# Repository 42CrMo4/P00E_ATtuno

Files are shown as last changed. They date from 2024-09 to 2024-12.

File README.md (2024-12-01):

# KiCad ATtuno Dev board

The ATtuno is a dev board for ATtiny 1 series microcontroller, loosely based on the UNO form factor. 

## Description

The ATtuno is an excellent starting point for those looking to explore the ATtiny 1 series microcontroller platform. 
Inspired by the familiar Arduino Uno form factor, this board offers a user-friendly approach to working with ATtiny Series 1 MCUs.
Key features:

- Arduino Uno-inspired layout
- Generous board size for comfortable handling
- Robust Wago clamping pin headers for secure connections
- Designed for quick start and rapid prototyping
- 3.3V and 5V compatible

This dev board bridges the gap between the popular Arduino ecosystem and the powerful, efficient ATtiny Series 1 microcontrollers. 
Its thoughtful design allows both beginners and experienced makers to quickly dive into projects without the need for delicate handling or specialized tools.

### Goal

The goal of the project will be:
- [ ] **undefined** - not known what the project will bring 
- [ ] **learn** - personally learn something new, no usefull outcome expected
- [ ] **prototype** - a working prototype or mvp
- [x] **80-20-rule** - 80% outcome with 20% effort
- [ ] **Product** - lets see :wink:

## KiCanvas 

view the project files in the browaser without downloading or installing anything via [KiCanvas](https://kicanvas.org)

[Main branche - Development](https://kicanvas.org/?github=https%3A%2F%2Fgithub.com%2F42CrMo4%2FP00E_ATtuno)

[v3.0](https://kicanvas.org/?github=https%3A%2F%2Fgithub.com%2F42CrMo4%2FP00E_ATtuno%2Ftree%2Fv3.0)

[v2.0](https://kicanvas.org/?github=https%3A%2F%2Fgithub.com%2F42CrMo4%2FP00E_ATtuno%2Ftree%2Fv2.0)

[v1.0](https://kicanvas.org/?github=https%3A%2F%2Fgithub.com%2F42CrMo4%2FP00E_ATtuno%2Ftree%2Fv1.0)

## Rendering (V3.0)

| Font | Back |
| --- | --- |
|PCB Top design|PCB Back design|

If you are looking for the latest Release with all the artifacts please visit the Release Page

## Rendering & BOM (Dev)

The renderings and BOM below are the uptodate state of the main branche.

| Font | Back |
|---|---|
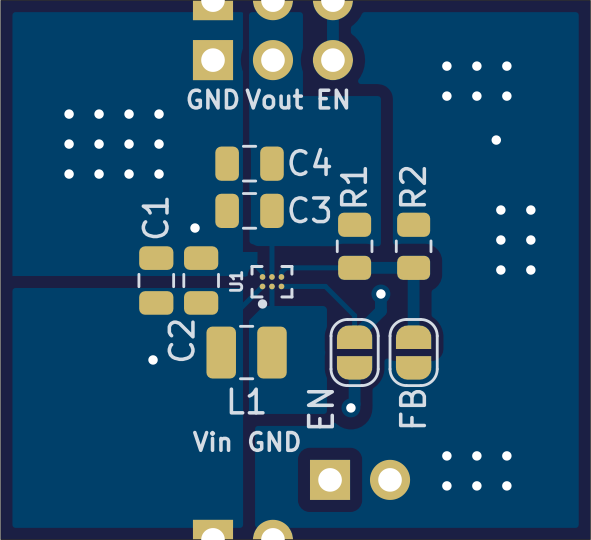
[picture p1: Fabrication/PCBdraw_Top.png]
PCB Top design
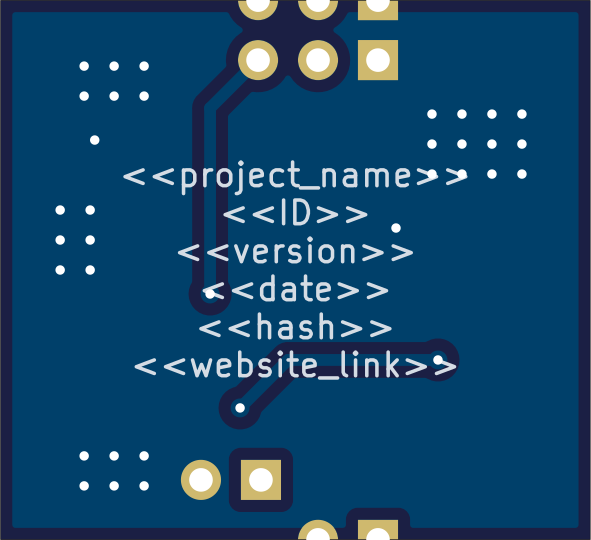
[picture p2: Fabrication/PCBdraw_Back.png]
PCB Back design
|  |  |

Link to the current BOM

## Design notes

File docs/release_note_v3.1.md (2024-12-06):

| Font | Back |
| --- | --- |
|PCB Top design|PCB Back design|

Bug Fix for Rlease Output.
No change to Schmatic or Board files

Changes
* Add Footprint Value to JLPCB Gerbers

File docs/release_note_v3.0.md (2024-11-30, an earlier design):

| Font | Back |
| --- | --- |
|PCB Top design|PCB Back design|

first RC release

New
* Added ATtiny1616 in QFN package as an option
* Added MOSFETS for the LEDs 
* Added programming capacitor for the CP2105 (see #4)
* Added Test Points 

Changes
* use PA4 / PA5 for the LEDs as this pins have PWM (see #2)
* decouple CP2105 from direct VBUS and use the DPDT switch (see #5)
* Footprint for the DPDT to habe a secound source option
* more information for BOM and components

Breaking Changes
* removed jumper for LEDs
* stencil fom v2.0 mostly not compatible

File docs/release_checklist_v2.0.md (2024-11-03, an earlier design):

Check before releasing and/or submitting to FAB
- [x] DRC/ERC passing (no Errors)
- [x] check for unconnected Traces
- [x] Groundplanes (newly) filled
- [x] Dimension Outline
- [x] Mounting Holes
- [x] Clearance for Connectors
- [x] Clearance for Housing
- [x] Clearance for generell
- [x] Component Labels
- [x] Labels not over VIA or Holes etc. 
- [x] Label Important (All) Pins — Both Sides
- [x] Revision number of Checklist will match the Git tag
- [x] Double check the final files
- [x] Fill Changelog (release_note.md)
- [x] projekt.properties filled correctly
- [x] Weblink / version / Date / name present SCH
- [x] Weblink / version / Date / name present PCB
- [x] Power Trace correct width
- [x] decoupling capacitors present
- [x] component orientation correct (MCU, Diod, etc)

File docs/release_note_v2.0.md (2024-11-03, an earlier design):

| Font | Back |
| --- | --- |
|PCB Top design|PCB Back design|

This is the 2nd iteration with a lot of improvmenets. 

New
* CP2105 USB to UPDI and UART
* StemmaQT Connector
* 4x4 WS2812b Grid 
* Dual Connectors for Pins and Slide Switches
* Mounting Holes M2.5
* TVS USB protection
* Test Points 
* Test Points with Hooks

Changes
* Silkscreen Updates for better Information

Breaking Changes
* Solder Stencil form v1.0 (many components have a diffent position and some new)
* use LED Pins PB0, PB1, PC0
* use RX/TX main Pins PB2, PB3 instead of secondary

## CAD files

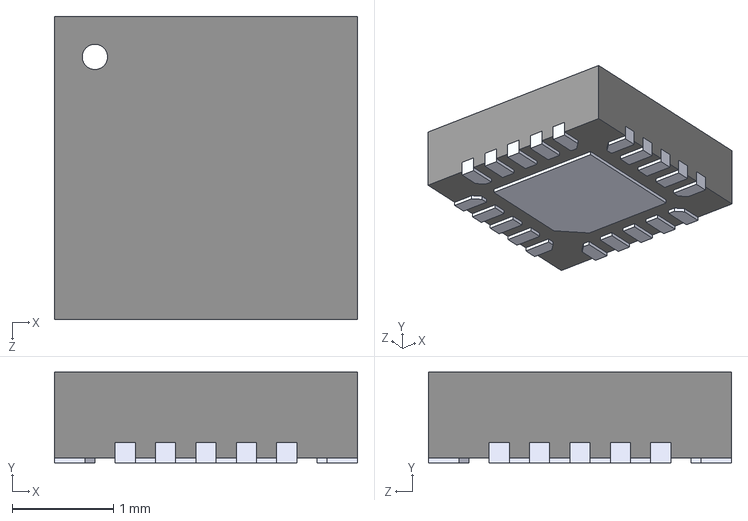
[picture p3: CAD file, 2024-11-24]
3d-models/ATTINY1616-MFR.step
3.00 x 0.9 x 3.00 mm

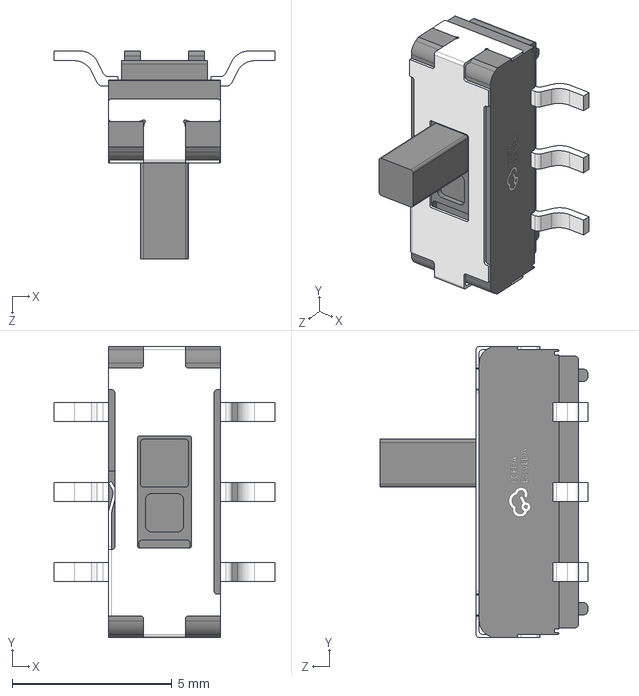
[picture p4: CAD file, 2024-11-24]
3d-models/SW-SMD_K3-2235S-K1.step
6.90 x 9.10 x 6.50 mm
翋极
褲极

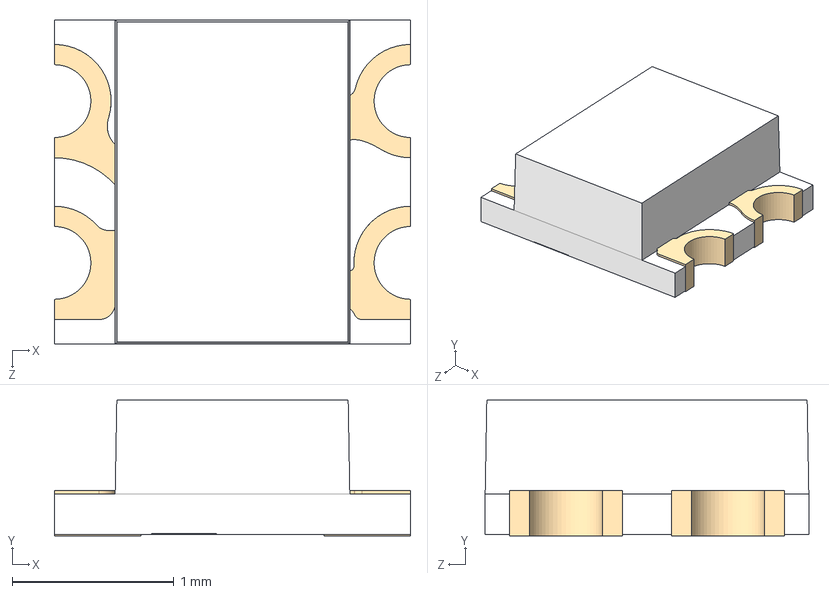
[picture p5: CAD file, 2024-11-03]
3d-models/WS2812B-2020.step
2.20 x 0.84 x 2.00 mm

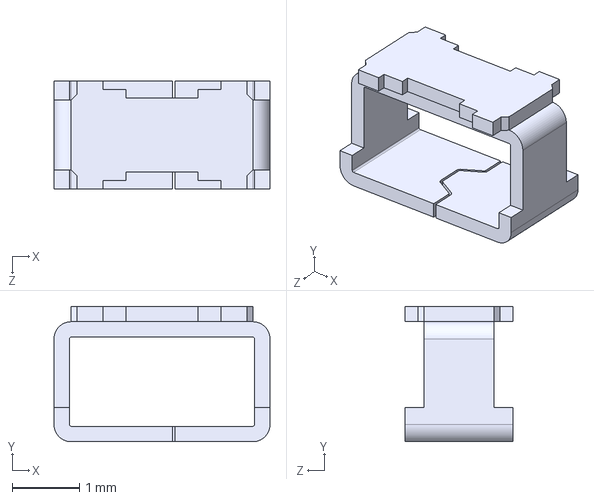
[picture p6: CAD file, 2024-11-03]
3d-models/RCWCTE.step
3.20 x 2.01 x 1.60 mm

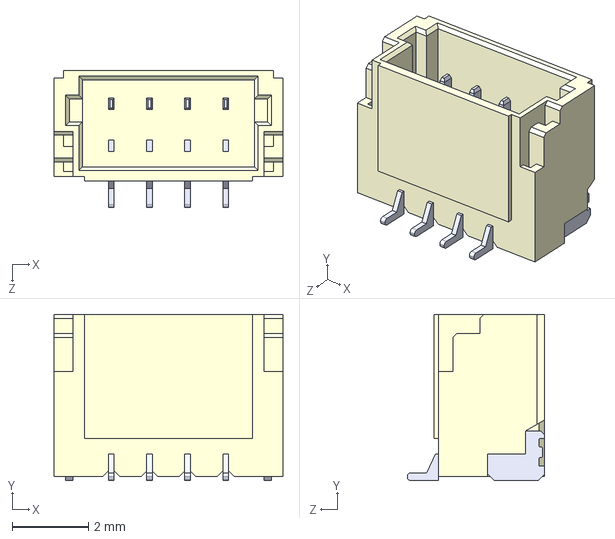
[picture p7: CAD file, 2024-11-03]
3d-models/BM04B-SRSS-TB_LF__SN_.step
6.00 x 4.35 x 3.60 mm

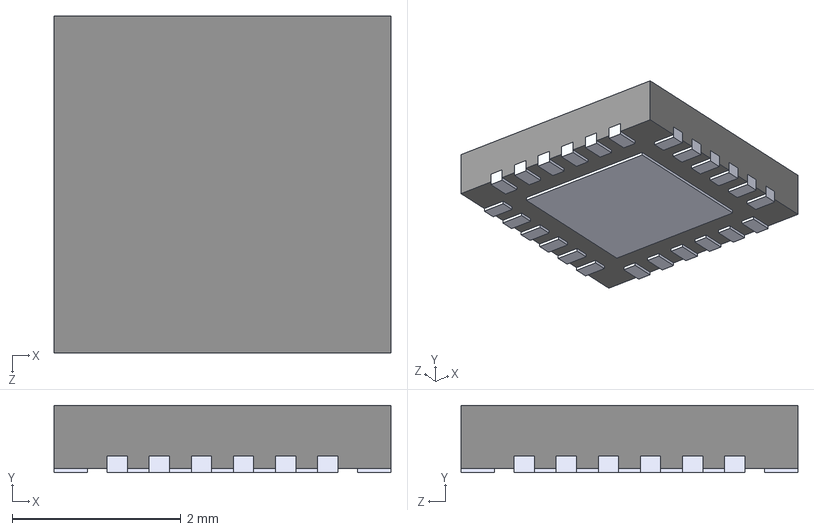
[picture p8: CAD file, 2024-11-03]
3d-models/CP2105.step
4.00 x 0.8 x 4.00 mm

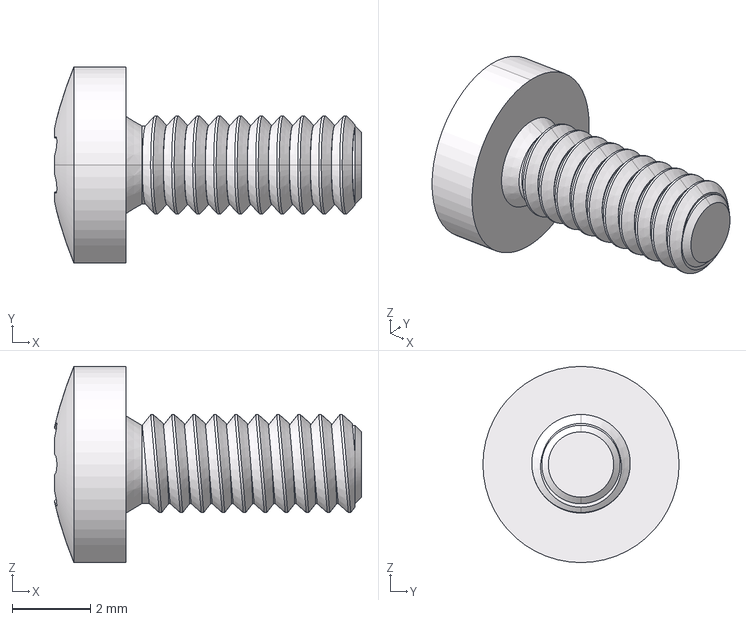
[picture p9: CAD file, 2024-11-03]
3d-models/Wuerth_0046662506_DIN_7985_aehnlich_Stahl_8.8_verzinkt_TX_LOD_High_1.stp
7.83 x 5.00 x 5.00 mm

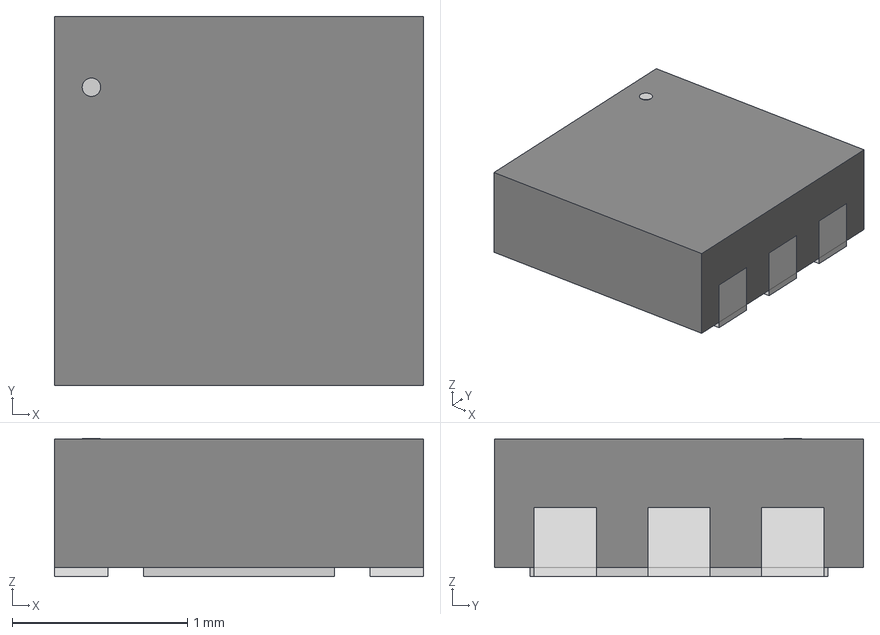
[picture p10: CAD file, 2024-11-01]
3d-models/DFN2X2-6-A_TPK.step
2.11 x 2.11 x 0.79 mm

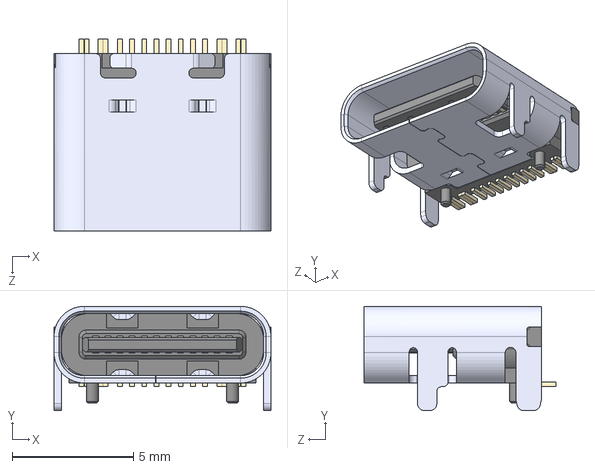
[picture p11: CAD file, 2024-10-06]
3d-models/TYPE-C-31-M-12.step
8.94 x 4.30 x 7.90 mm

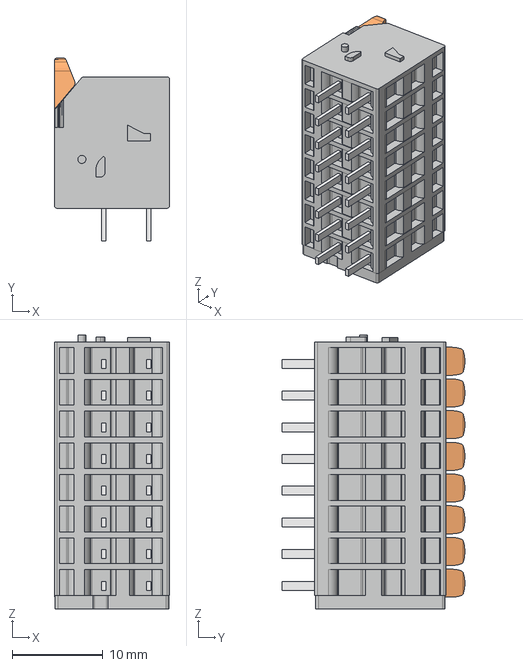
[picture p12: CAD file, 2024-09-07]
3d-models/2601-3108.stp
12.8 x 20.2 x 30.2 mm

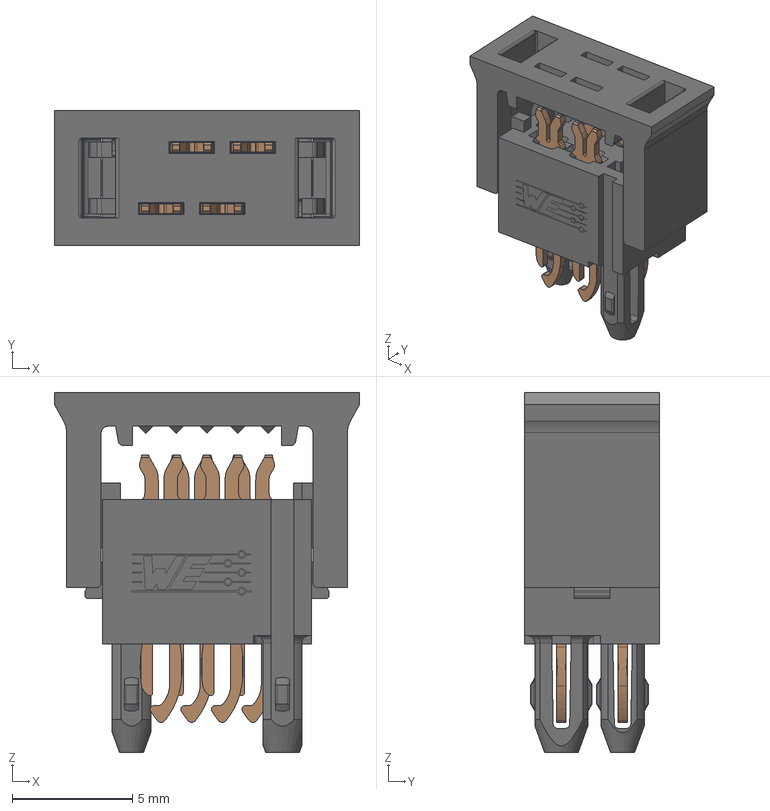
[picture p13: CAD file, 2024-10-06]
3d-models/490107670412.stp
12.7 x 5.60 x 15.0 mm
CT422_00.4.1.1_0 x 4
BS698_4_00.4_0000_0
BS697_4_00.6_0000_0

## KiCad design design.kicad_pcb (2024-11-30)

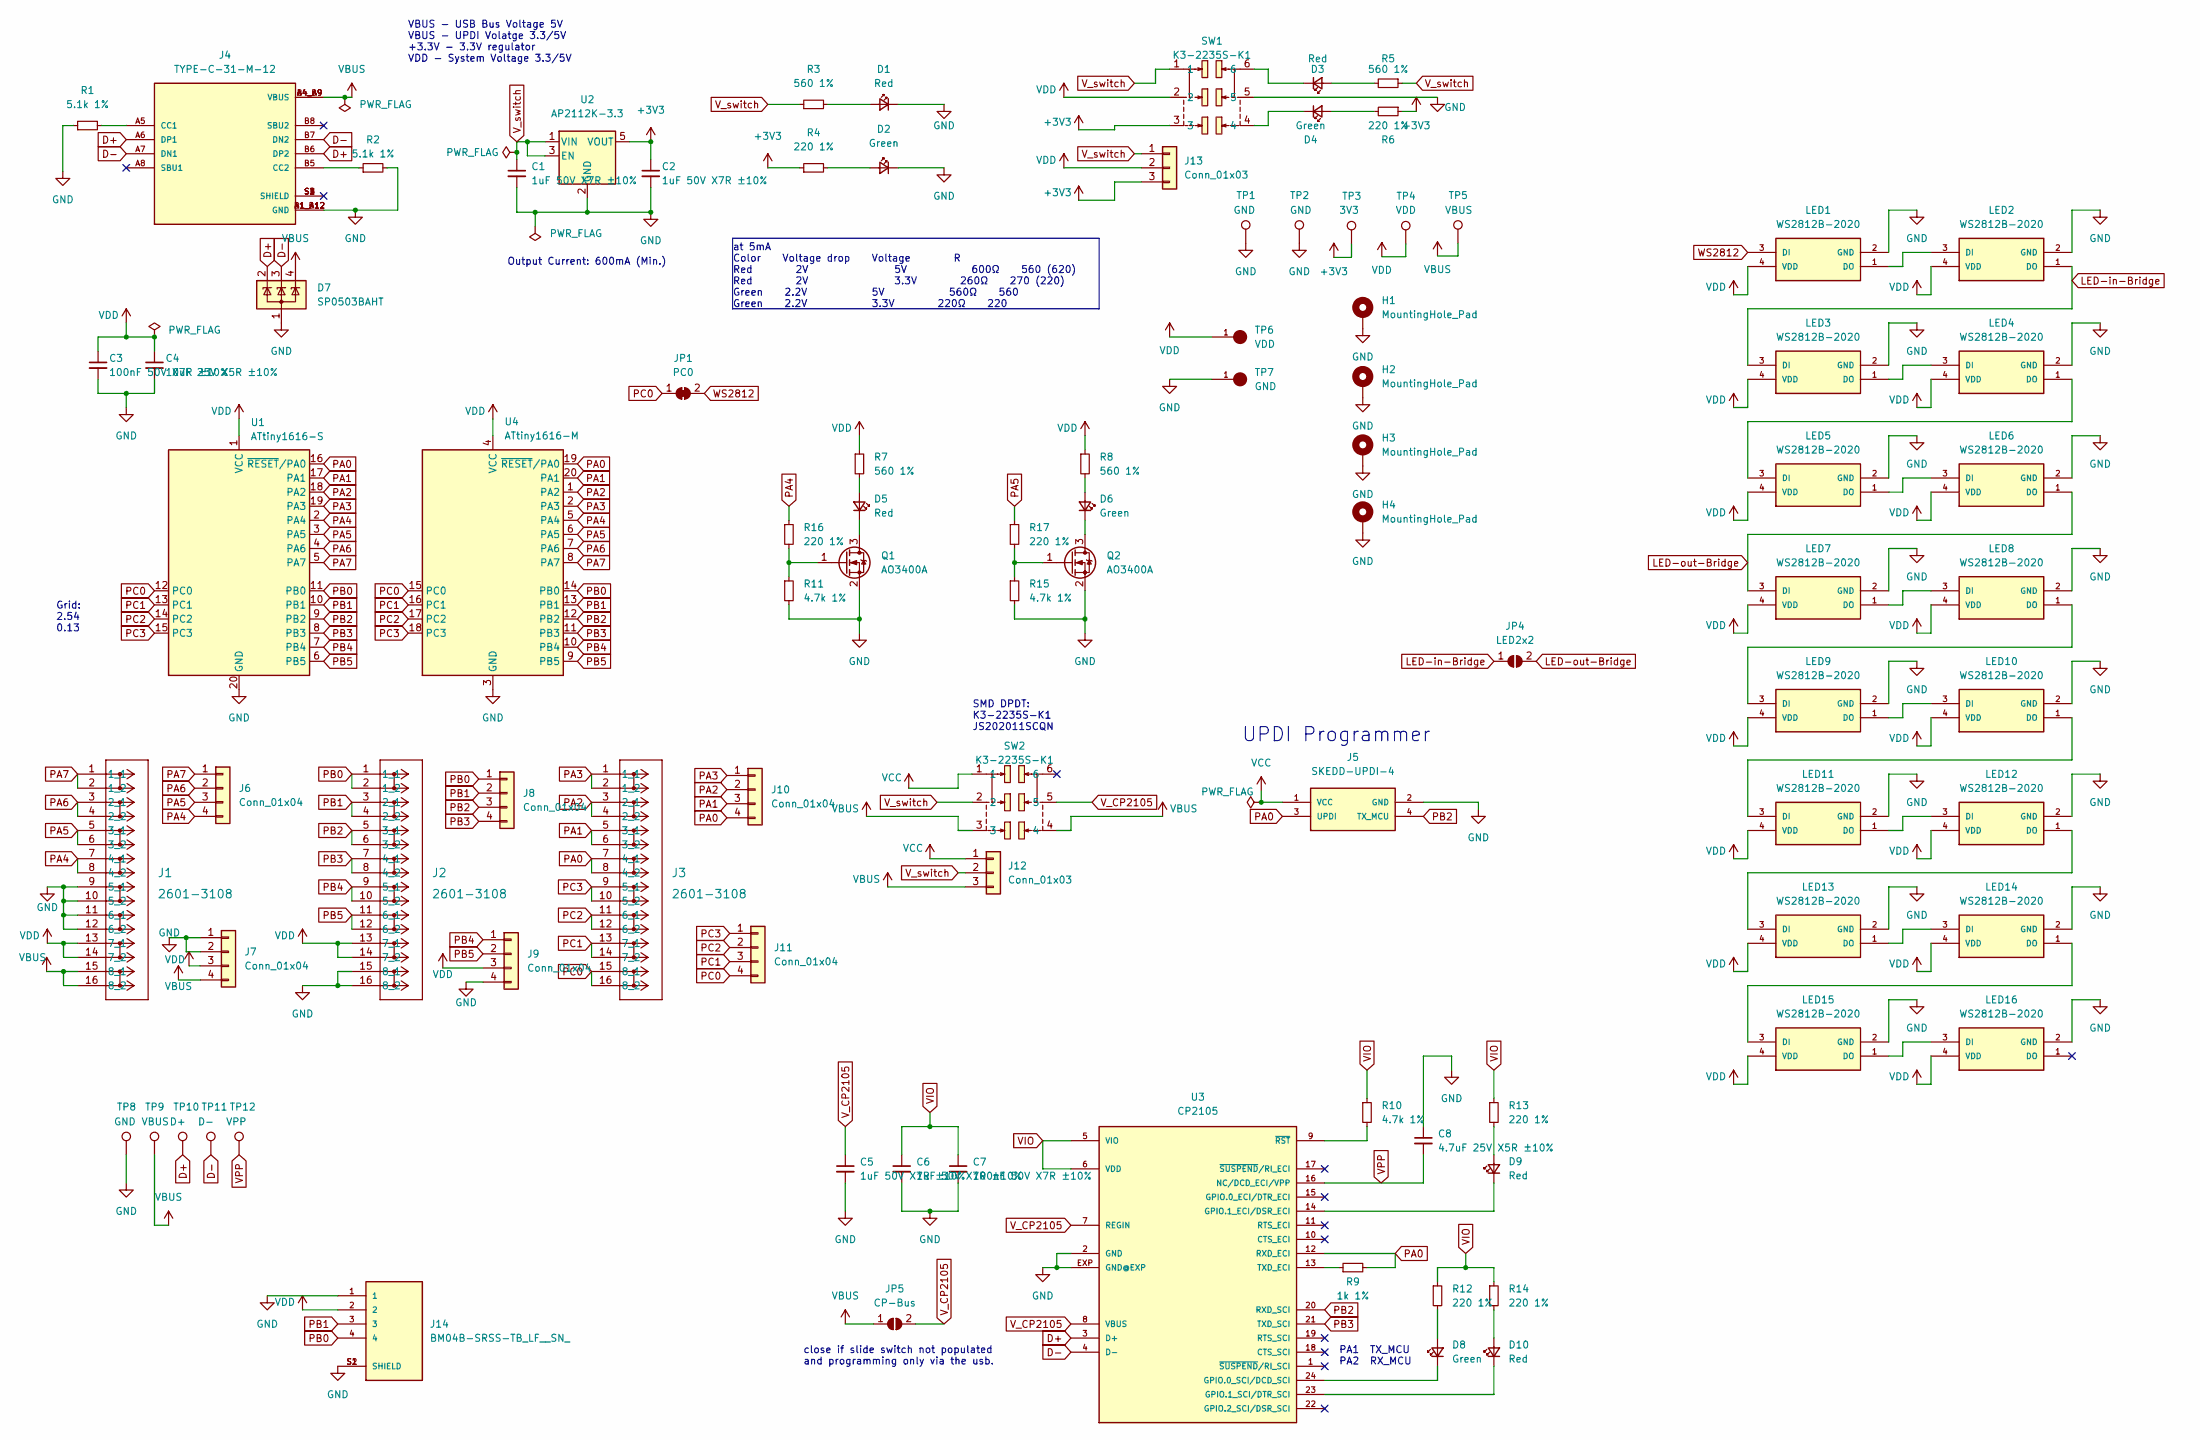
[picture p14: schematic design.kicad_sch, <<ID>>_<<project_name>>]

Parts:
C1, C2, C5, C6: 1uF 50V X7R ±10%; C_0805_2012Metric; MANUFACTURER_PART_NUMBER CL21B105KBFNNNE; JLCPCB C28323
C3, C7: 100nF 50V X7R ±10%; C_0805_2012Metric; MANUFACTURER_PART_NUMBER CC0805KRX7R9BB104; JLCPCB C49678
C4: 10uF 25V X5R ±10%; C_0805_2012Metric; MANUFACTURER_PART_NUMBER CL21A106KAYNNNE; JLCPCB C15850
C8: 4.7uF 25V X5R ±10%; C_0805_2012Metric; MANUFACTURER_PART_NUMBER CL21A475KAQNNNE; JLCPCB C1779
D1, D3, D5, D9, D10: Red; LED_0805_2012Metric; MANUFACTURER_PART_NUMBER NCD0805R1; JLCPCB C84256
D2, D4, D6, D8: Green; LED_0805_2012Metric; MANUFACTURER_PART_NUMBER KT-0805G; JLCPCB C2297
D7: SP0503BAHT; SOT-143; MANUFACTURER_PART_NUMBER SP0503BAHTG; JLCPCB C3040626
H1, H2, H3, H4: MountingHole_Pad; MountingHole_2.7mm_M2.5_Pad_Via
J1, J2, J3: 2601-3108; CONN8_2601-3108_WAG
J4: TYPE-C-31-M-12; TYPE-C-31-M-12_HRO_TYPE-C-31-M-12; PARTREV 2020.12.08; JLCPCB C165948
J5: SKEDD-UPDI-4
J6, J7, J8, J9, J10, J11: Conn_01x04; PinHeader_1x04_P2.54mm_Vertical
J12, J13: Conn_01x03; PinHeader_1x03_P2.54mm_Vertical
J14: BM04B-SRSS-TB_LF__SN_; BM04B-SRSS-TB_LF__SN__JST_BM04B-SRSS-TB_LF__SN_; PARTREV N/A; JLCPCB C160390
JP1: PC0; SolderJumper-2_P1.3mm_Bridged_Pad1.0x1.5mm
JP4: LED2x2; SolderJumper-2_P1.3mm_Open_Pad1.0x1.5mm
JP5: CP-Bus; SolderJumper-2_P1.3mm_Open_Pad1.0x1.5mm
LED1, LED2, LED3, LED4, LED5, LED6, LED7, LED8, LED9, LED10, LED11, LED12, LED13, LED14, LED15, LED16: WS2812B-2020; WS2812B2020; MANUFACTURER_PART_NUMBER WS2812B-2020; JLCPCB C965555
Q1, Q2: AO3400A; SOT-23; MANUFACTURER_PART_NUMBER AO3400A; JLCPCB C20917
R1, R2: 5.1k 1%; R_0805_2012Metric; MANUFACTURER_PART_NUMBER C27834; JLCPCB C27834
R3, R5, R7, R8: 560 1%; R_0805_2012Metric; MANUFACTURER_PART_NUMBER 0805W8F5600T5E; JLCPCB C28636
R4, R6, R12, R13, R14, R16, R17: 220 1%; R_0805_2012Metric; MANUFACTURER_PART_NUMBER 0805W8F2200T5E; JLCPCB C17557
R9: 1k 1%; R_0805_2012Metric; MANUFACTURER_PART_NUMBER 0805W8F1001T5E; JLCPCB C17513
R10, R11, R15: 4.7k 1%; R_0805_2012Metric; MANUFACTURER_PART_NUMBER 0805W8F4701T5E; JLCPCB C17673
SW1, SW2: K3-2235S-K1; easyeda2kicad_SW-SMD_K3-2235S-K1; MANUFACTURER_PART_NUMBER K3-2235S-K1; LCSC Part C145845
TP1, TP2, TP8: GND; TestPoint_Pad_D2.5mm
TP3: 3V3; TestPoint_Pad_D2.5mm
TP4: VDD; TestPoint_Pad_D2.5mm
TP5, TP9: VBUS; TestPoint_Pad_D2.5mm
TP6: VDD; RCWCTE_TP420X150; PARTREV 1/06/14
TP7: GND; RCWCTE_TP420X150; PARTREV 1/06/14
TP10: D+; TestPoint_Pad_D2.5mm
TP11: D-; TestPoint_Pad_D2.5mm
TP12: VPP; TestPoint_Pad_D2.5mm
U1: ATtiny1616-S; SOIC-20W_7.5x12.8mm_P1.27mm; MANUFACTURER_PART_NUMBER ATTINY1616-SN; JLCPCB C614136
U2: AP2112K-3.3; SOT-23-5; MANUFACTURER_PART_NUMBER TPAP2112K-3.3TRG1; JLCPCB C3021085
U3: CP2105; CP2105_QFN24_0.5; MANUFACTURER_PART_NUMBER CP2105-F01-GMR; JLCPCB C109102
U4: ATtiny1616-M; ATTINY1616-MFR_QFN40P300X300X90-21N; MANUFACTURER_PART_NUMBER ATTINY1616-MNR; JLCPCB C507118

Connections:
+3V3: C2.1, J13.3, R4.1, R6.1, SW1.3, TP3.1, U2.5 (VOUT)
D+: D7.2 (K), J4.A6 (DP1), J4.B6 (DP2), TP10.1, U3.3 (D+)
D-: D7.3 (K), J4.A7 (DN1), J4.B7 (DN2), TP11.1, U3.4 (D-)
GND: C1.2, C2.2, C3.2, C4.2, C5.2, C6.2, C7.2, C8.1, D1.1 (K), D2.1 (K), D7.1 (A), H1.1, H2.1, H3.1, H4.1, J1.9 (5_1), J1.10 (5_2), J1.11 (6_1), J1.12 (6_2), J2.15 (8_1), J2.16 (8_2), J4.A1_B12 (GND), J4.B1_A12 (GND), J5.2 (GND), J7.1, J7.2, J9.4, J14.1, J14.S1 (SHIELD), J14.S2 (SHIELD), LED1.2 (GND), LED2.2 (GND), LED3.2 (GND), LED4.2 (GND), LED5.2 (GND), LED6.2 (GND), LED7.2 (GND), LED8.2 (GND), LED9.2 (GND), LED10.2 (GND), LED11.2 (GND), LED12.2 (GND), LED13.2 (GND), LED14.2 (GND), LED15.2 (GND), LED16.2 (GND), Q1.2 (S), Q2.2 (S), R1.1, R2.2, R11.2, R15.2, SW1.5, TP1.1, TP2.1, TP7.1, TP8.1, U1.20 (GND), U2.2 (GND), U3.2 (GND), U3.EXP (GND@EXP), U4.3 (GND), U4.21 (GND)
LED-in-Bridge: JP4.1 (A), LED2.1 (DO), LED3.3 (DI)
LED-out-Bridge: JP4.2 (B), LED6.1 (DO), LED7.3 (DI)
unnamed: D1.2 (A), R3.2
unnamed: D2.2 (A), R4.2
unnamed: D3.1 (K), SW1.6
unnamed: D3.2 (A), R5.2
unnamed: D4.1 (K), SW1.4
unnamed: D4.2 (A), R6.2
unnamed: D5.1 (K), Q1.3 (D)
unnamed: D6.1 (K), Q2.3 (D)
unnamed: D8.1 (K), U3.24 (GPIO.0_SCI/DCD_SCI)
unnamed: D8.2 (A), R12.2
unnamed: D9.1 (K), U3.14 (GPIO.1_ECI/DSR_ECI)
unnamed: D9.2 (A), R13.2
unnamed: D10.1 (K), U3.23 (GPIO.1_SCI/DTR_SCI)
unnamed: D10.2 (A), R14.2
unnamed: J4.A5 (CC1), R1.2
unnamed: J4.B5 (CC2), R2.1
unnamed: LED1.1 (DO), LED2.3 (DI)
unnamed: LED3.1 (DO), LED4.3 (DI)
unnamed: LED4.1 (DO), LED5.3 (DI)
unnamed: LED5.1 (DO), LED6.3 (DI)
unnamed: LED7.1 (DO), LED8.3 (DI)
unnamed: LED8.1 (DO), LED9.3 (DI)
unnamed: LED10.1 (DO), LED11.3 (DI)
unnamed: LED9.1 (DO), LED10.3 (DI)
unnamed: LED11.1 (DO), LED12.3 (DI)
unnamed: LED12.1 (DO), LED13.3 (DI)
unnamed: LED13.1 (DO), LED14.3 (DI)
unnamed: LED14.1 (DO), LED15.3 (DI)
unnamed: LED15.1 (DO), LED16.3 (DI)
unnamed: Q1.1 (G), R11.1, R16.2
unnamed: Q2.1 (G), R15.1, R17.2
unnamed: D5.2 (A), R7.2
unnamed: D6.2 (A), R8.2
unnamed: R9.1, U3.13 (TXD_ECI)
unnamed: R10.2, U3.9 (~RST)
PA0: J3.7 (4_1), J3.8 (4_2), J5.3 (UPDI), J10.4, R9.2, U1.16 (~RESET/PA0), U3.12 (RXD_ECI), U4.19 (~RESET/PA0)
PA1: J3.5 (3_1), J3.6 (3_2), J10.3, U1.17 (PA1), U4.20 (PA1)
PA2: J3.3 (2_1), J3.4 (2_2), J10.2, U1.18 (PA2), U4.1 (PA2)
PA3: J3.1 (1_1), J3.2 (1_2), J10.1, U1.19 (PA3), U4.2 (PA3)
PA4: J1.7 (4_1), J1.8 (4_2), J6.4, R16.1, U1.2 (PA4), U4.5 (PA4)
PA5: J1.5 (3_1), J1.6 (3_2), J6.3, R17.1, U1.3 (PA5), U4.6 (PA5)
PA6: J1.3 (2_1), J1.4 (2_2), J6.2, U1.4 (PA6), U4.7 (PA6)
PA7: J1.1 (1_1), J1.2 (1_2), J6.1, U1.5 (PA7), U4.8 (PA7)
PB0: J2.1 (1_1), J2.2 (1_2), J8.1, J14.4, U1.11 (PB0), U4.14 (PB0)
PB1: J2.3 (2_1), J2.4 (2_2), J8.2, J14.3, U1.10 (PB1), U4.13 (PB1)
PB2: J2.5 (3_1), J2.6 (3_2), J5.4 (TX_MCU), J8.3, U1.9 (PB2), U3.20 (RXD_SCI), U4.12 (PB2)
PB3: J2.7 (4_1), J2.8 (4_2), J8.4, U1.8 (PB3), U3.21 (TXD_SCI), U4.11 (PB3)
PB4: J2.9 (5_1), J2.10 (5_2), J9.1, U1.7 (PB4), U4.10 (PB4)
PB5: J2.11 (6_1), J2.12 (6_2), J9.2, U1.6 (PB5), U4.9 (PB5)
PC0: J3.15 (8_1), J3.16 (8_2), J11.4, JP1.1 (A), U1.12 (PC0), U4.15 (PC0)
PC1: J3.13 (7_1), J3.14 (7_2), J11.3, U1.13 (PC1), U4.16 (PC1)
PC2: J3.11 (6_1), J3.12 (6_2), J11.2, U1.14 (PC2), U4.17 (PC2)
PC3: J3.9 (5_1), J3.10 (5_2), J11.1, U1.15 (PC3), U4.18 (PC3)
VBUS: D7.4 (K), J1.15 (8_1), J1.16 (8_2), J4.A4_B9 (VBUS), J4.B4_A9 (VBUS), J7.4, J12.3, JP5.1 (A), SW2.3, SW2.4, TP5.1, TP9.1
VCC: J5.1 (VCC), J12.1, SW2.1
VDD: C3.1, C4.1, J1.13 (7_1), J1.14 (7_2), J2.13 (7_1), J2.14 (7_2), J7.3, J9.3, J13.2, J14.2, LED1.4 (VDD), LED2.4 (VDD), LED3.4 (VDD), LED4.4 (VDD), LED5.4 (VDD), LED6.4 (VDD), LED7.4 (VDD), LED8.4 (VDD), LED9.4 (VDD), LED10.4 (VDD), LED11.4 (VDD), LED12.4 (VDD), LED13.4 (VDD), LED14.4 (VDD), LED15.4 (VDD), LED16.4 (VDD), R7.1, R8.1, SW1.2, TP4.1, TP6.1, U1.1 (VCC), U4.4 (VCC)
VIO: C6.1, C7.1, R10.1, R12.1, R13.1, R14.1, U3.5 (VIO), U3.6 (VDD)
VPP: C8.2, TP12.1, U3.16 (NC/DCD_ECI/VPP)
V_CP2105: C5.1, JP5.2 (B), SW2.5, U3.7 (REGIN), U3.8 (VBUS)
V_switch: C1.1, J12.2, J13.1, R3.1, R5.1, SW1.1, SW2.2, U2.1 (VIN), U2.3 (EN)
WS2812: JP1.2 (B), LED1.3 (DI)

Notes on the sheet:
VBUS - USB Bus Voltage 5V VBUS - UPDI Volatge 3.3/5V +3.3V - 3.3V regulator VDD - System Voltage 3.3/5V
at 5mA Color Voltage drop Voltage R Red 2V 5V 600Ω 560 (620) Red 2V 3.3V 260Ω 270 (220) Green 2.2V 5V 560Ω 560 Green 2.2V 3.3V 220Ω 220
Output Current: 600mA (Min.)
close if slide switch not populated and programming only via the usb.
PA1 TX_MCU PA2 RX_MCU
SMD DPDT: K3-2235S-K1 JS202011SCQN
Grid: 2.54 0.13
UPDI Programmer

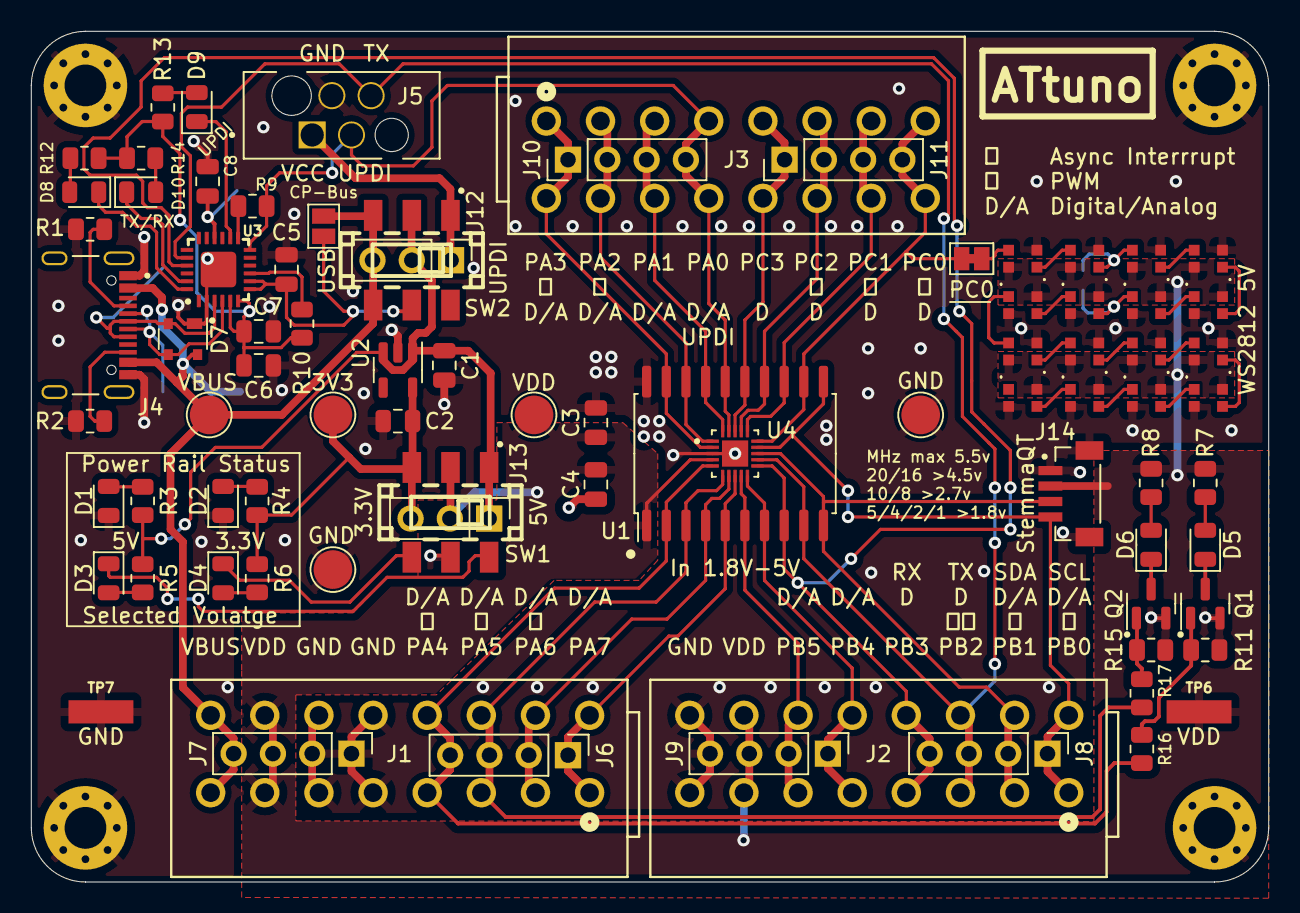
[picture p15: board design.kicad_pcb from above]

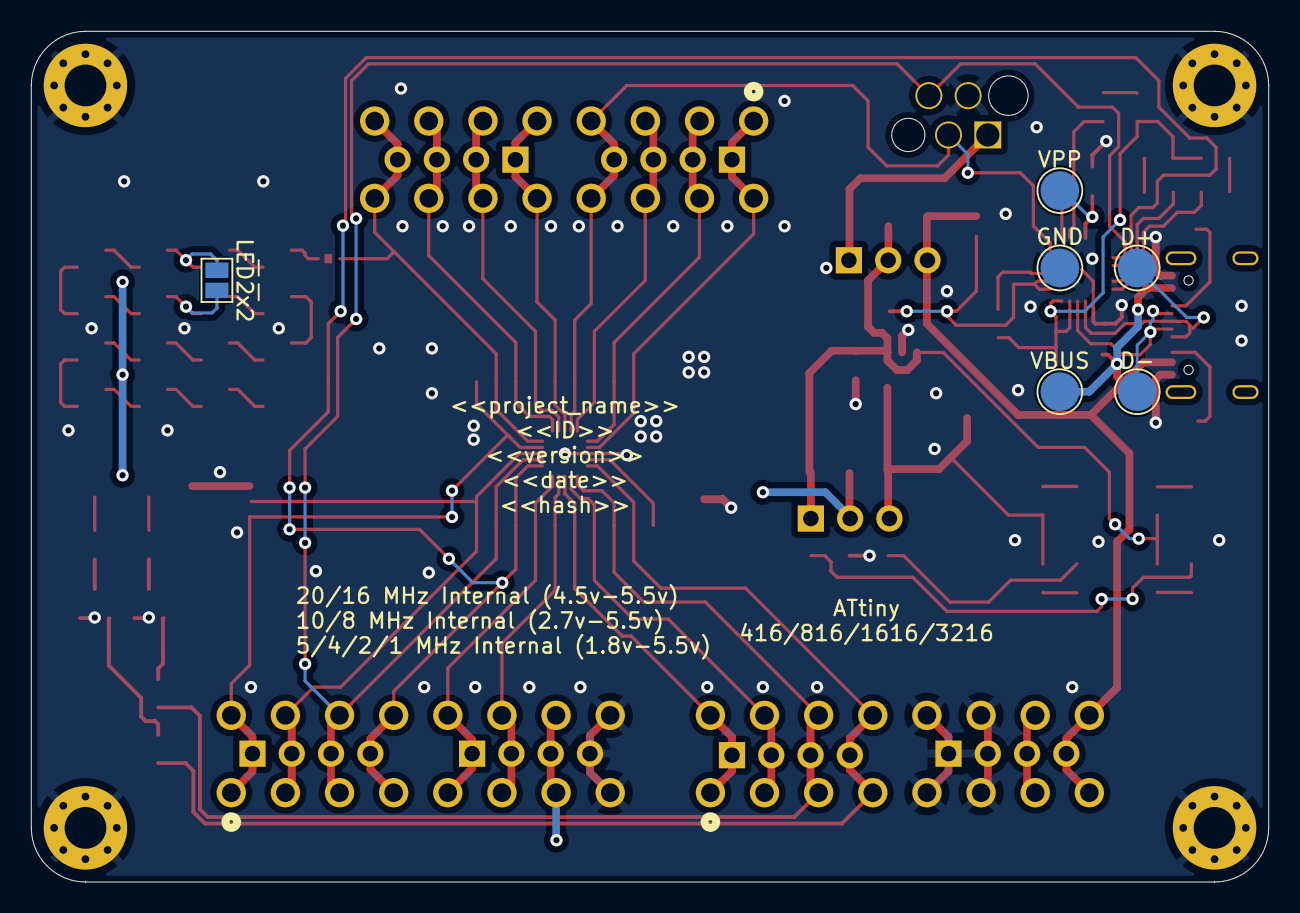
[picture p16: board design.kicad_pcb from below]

Board: 2 copper layers, 80.0 x 55.0 mm, 92 parts (6 on the bottom side), 67 nets.

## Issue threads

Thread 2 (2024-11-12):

LEDs are on TX/RX pins

42CrMo4, 2024-11-12:
PB2 and PB3 are used for the LEDs and are also the TX/RX Pins. Also the Silkscreen is wrong on both.
Use diffrent Pins with PWM support.

Closed 2024-11-13.

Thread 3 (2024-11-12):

Power is not disconnected by S2

42CrMo4, 2024-11-12:
powering by USB and switching to the UPDI header will not cut power. Need to find the power path.

Closed 2024-11-13.

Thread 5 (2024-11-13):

make power input for CP2105 switchable with pinheaders

42CrMo4, 2024-11-13:
The commit https://github.com/42CrMo4/P00E_ATtuno/commit/0422c162f86245addd4954adcf484739a966c1d8 should fix the problem in #3 but introduces a new problem as this will not work with the header J12 option as then the CP2105 has not power at all.

Closed 2024-11-14.

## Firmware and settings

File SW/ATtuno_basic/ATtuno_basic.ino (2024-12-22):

#include <tinyNeoPixel.h>

#define LED_PIN PIN_PC0
#define NUM_LEDS 16
#define TOGGLE_PIN_1 PIN_PA4
#define TOGGLE_PIN_2 PIN_PA5

// Create neopixel object
tinyNeoPixel pixels = tinyNeoPixel(NUM_LEDS, LED_PIN, NEO_GRB);

// Array to map physical LED positions to logical positions due to serpentine wiring
const uint8_t ledMap[NUM_LEDS] = {
  0,  1,  2,  3,      // First row ->
  7,  6,  5,  4,      // Second row <-
  8,  9,  10, 11,     // Third row ->
  15, 14, 13, 12      // Fourth row <-
};

void setup() {
  // Initialize neopixel library
  pixels.begin();

  // Clear all pixels
  pixels.clear();
  pixels.show();

  tinypixel();

  // Configure toggle pins as outputs
  pinMode(TOGGLE_PIN_1, OUTPUT);
  pinMode(TOGGLE_PIN_2, OUTPUT);
}

void loop() {
  // Toggle PA4
  analogWrite(TOGGLE_PIN_1, 10);
  delay(500);
  analogWrite(TOGGLE_PIN_1, 0);
  delay(500);

  // Toggle PA5
  analogWrite(TOGGLE_PIN_2, 5);
  delay(500);
  analogWrite(TOGGLE_PIN_2, 0);
  delay(500);

  tinypixel();
}

void tinypixel() {
  // Light up LEDs one by one with a blue color
  pixels.clear();
  for (int i = 0; i < NUM_LEDS; i++) {
    pixels.setPixelColor(ledMap[i], pixels.Color(0, 0, 5)); // Blue color at medium brightness
    pixels.show();
    delay(50); // Wait 100ms between each LED
  }
}

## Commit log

2024-09-07 setup the repo
    [TPS61099xYFFT.step, design.kicad_pcb, design.kicad_sch]
2024-10-03 many changes
    [design.kicad_pcb, design.kicad_sch]
2024-10-06 lot of updates
    [design.kicad_pcb, design.kicad_sch]
2024-10-06 update edge layer
    [design.kicad_pcb]
2024-10-06 add 3D files
    [490107670412.stp, TYPE-C-31-M-12.step]
2024-10-06 DEL unneeded 3D File
    [LM73100RPWR.step]
2024-10-06 new stuff
    [design.kicad_pcb]
2024-10-06 DEL unneeded
    [design-bom-short.csv, design-bom.csv]
2024-10-06 ERC correction
    Warnings are everywhere
    [design.kicad_sch]
2024-10-06 DRC correction
    [design.kicad_pcb]
2024-10-06 mirror property text on the back, remove weblink
    [design.kicad_pcb]
2024-10-21 small updates
    silkscreen update,
    via not over silkscreen,
    connect GND planes
    [design.kicad_pcb]
2024-10-21 connect ground plane by moving routing
    [design.kicad_pcb]
2024-10-23 SCH additions
    Mounting holes
    Test Pads
    01x04 pinheaders
    [design.kicad_sch]
2024-10-23 ADD CP2105
    Add a new USB2UART Sheet
    [USB2UART.kicad_sch, design.kicad_sch]
2024-10-23 remove subsheet USB2UART
    [USB2UART.kicad_sch, design.kicad_sch]
2024-10-25 SCH add designator and footprints
    [design.kicad_sch]
2024-11-02 many updates
    [design.kicad_pcb, design.kicad_sch]
2024-11-03 consolidate traces
    [design.kicad_pcb]
2024-11-03 add LED color and Parameters
    [design.kicad_sch]
2024-11-03 Add TVS Diode to USB
    [design.kicad_pcb, design.kicad_sch]
2024-11-03 add GND via cp2105
    [design.kicad_pcb]
2024-11-03 change to BM04B-SRSS-TB symbol
    [design.kicad_pcb, design.kicad_sch]
2024-11-03 update LED resistor values
    [design.kicad_pcb, design.kicad_sch]
2024-11-03 change LEDs to pin PB2/PB3 not to use the i2c pins
    [design.kicad_pcb, design.kicad_sch]
2024-11-13 Route LEDs to own pins
    closes #2
    Use PA4 and PA5 for the LEDs. This pins have PWM and are not used.
    correct the silk screen.
    [design.kicad_pcb, design.kicad_sch]
2024-11-13 fix VDD plane
    [design.kicad_pcb]
2024-11-13 Arrange TestPoints in a grid. Correct small traces.
    [design.kicad_pcb]
2024-11-13 update silkscreen
    [design.kicad_pcb]
2024-11-13 use switchable power input for CP2105
    closes #3
    is not compatible with header pins only on J12
    [design.kicad_pcb, design.kicad_sch]
2024-11-13 move C2 closer to U2
    [design.kicad_pcb]
2024-11-13 small trace fix
    [design.kicad_pcb]
2024-11-13 align R1/R2 around USB connector
    [design.kicad_pcb]
2024-11-13 correct DRC issues
    [design.kicad_pcb]
2024-11-14 add CP2105 VBus solderbridge
    closes #5
    [design.kicad_pcb, design.kicad_sch]
2024-11-15 add programming capacitor
    closes #4
    to use the TX/RX LEDs the cp2105 must be programmed to use this function (only one time possible). Todo this a 4,7uF capacitor must be used on pin VPP according to the Datasheet Note 4 page 18.
    [design.kicad_pcb, design.kicad_sch]
2024-11-15 add designators
    [design.kicad_sch]
2024-11-15 add note for jp5
    [design.kicad_sch]
2024-11-15 Add USB Programming interface
    Touchpoints on Back for USB, Power and VPP.
    VPP so the 4,7uF capacitor must not be populated and can be done with a programming rig.
    [design.kicad_pcb, design.kicad_sch]
2024-11-15 Add Silkscreen update
    Add information to the front.
    update various information.
    arrange it more neatly.
    [design.kicad_pcb]
2024-11-15 Updates testpoints
    make them align on full intervals
    add dimension marker
    [design.kicad_pcb]
2024-11-15 Add ATtiny QFN
    [design.kicad_pcb, design.kicad_sch]
2024-11-15 small minor updates
    DRC issues
    make traces lean
    [design.kicad_pcb]
2024-11-17 add component information
    capacitor additional values
    JLCPCB part #
    [design.kicad_sch]
2024-11-24 change to K3-2235S-K1 / JS202011SCQN DPDT Switch
    [design.kicad_pcb, design.kicad_sch]
2024-11-24 Add MOSFET for GPIO LEDs
    [design.kicad_pcb, design.kicad_sch]
2024-11-24 Add Gate Resistor MOSFET
    [design.kicad_pcb, design.kicad_sch]
2024-11-24 add Variants
    [design.kicad_sch]
2024-11-24 add LCSC numbers to correct column
    [design.kicad_sch]
2024-11-24 change to snapeda Footprint for QFN Attiny
    [design.kicad_sch]
2024-11-25 remove via
    [design.kicad_pcb]
2024-11-30 add PCBWAY
2024-11-30 add pin1 marker
    [design.kicad_pcb]
2024-11-30 add Mfg Part #
    [design.kicad_sch]
2024-11-30 add resistor variance
    [design.kicad_sch]
2024-11-30 DFM Check updates
    [design.kicad_pcb]
2024-11-30 fill PCB
    [design.kicad_pcb]
2024-12-01 Refactor WF and use Groups for outputs (#6)
    * DEL uneeded code
    * refactor variable replacement in kicad files
    * disable STEP generation
    * add group generation_output
    * disable SOIC Variant
    * remove new line
2024-12-06 print footprint values in jlcpcb
2024-12-06 Revert "print footprint values in jlcpcb"
    This reverts commit 624751174857fc160f60b685ec09f43c98517ca8.
2024-12-22 add basic Arduino sketch

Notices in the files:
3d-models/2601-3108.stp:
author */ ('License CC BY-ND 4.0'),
